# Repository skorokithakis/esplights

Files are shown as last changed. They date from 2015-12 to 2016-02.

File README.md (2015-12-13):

# ESPlights

This is a home automation controller and sensor that I wrote for my house.

It's mostly ad-hoc, but hopefully you'll find something here that will help you.

## Components

To make everything work, you need:

* A NodeMCU (that's what I used) or another compatible ESP8266 thing. An Arduino
  would probably also work.
* An infrared LED.
* A 433 MHz RF transmitter.
* An alarm (I used one of those magnetic window alarm thingies).
* An analog light sensor.
* A DHT11 temperature/humidity sensor.
* A pyroelectric IR motion sensor.

There are multiple components to this project, which will be explained below.

### A wifi-enabled MQTT client

I use the ESP8266 to connect to the home wifi network and from that to my MQTT
server, which allows all the below functionality to work. All the sensors and
transmitters report to and receive commands from MQTT topics.

### An RF transmitter

I bought some [RF-controlled
sockets](http://www.alibaba.com/product-detail/remote-control-socket-wireless-socket-rf_60038866245/showimage.html)
and decided to automate some lights in my house, so
I [reverse-engineered](http://www.stavros.io/posts/how-remote-control-rf-devices-raspberry-pi/)
the protocol and wrote some code to [control the lights
remotely](http://www.stavros.io/posts/control-rf-devices-with-arduino/). This is
why you need the RF transmitter. If you don't have those sockets, you can just
ignore that part of the code.

### A motion sensor

The motion sensor is used for the lights above, it turns them off if there's no
motion in X minutes and turns them back on if motion is detected.

### Light, temperature and humidity sensors

The light sensor is used for the lights too. If there's no light and there has
been motion lately, the lamp turns on, and it turns off if there's a lot of
light detected suddenly (it means that I turned some other light on).

The temperature and humidity sensors are just for fun.

### An alarm

The alarm is triggered if I have indicated that I'm not at home and motion is
detected. I also get a message on my phone, but all this is done with an
external script that is not included here.

### A universal IR remote control

Since I had this, I figured I'd write some code to control my TV and AC unit.
There's a helper script, `misc/esplights.py` that will:

* Transform timings, options, parameters, etc passed on the command line into a
  suitable format for the ESPlights controller to read.
* Enable and disable automation (whether lights are turned on or off
  automatically). This only lasts for a few hours before it times out.
* Activate and deactivate the alarm.
* Help you analyze timings. Pass it a CSV from a Saleae Logic export and it will
  print timings compatible with itself (for analyzing IR and RF signals).

The remote control protocol allows you to send any RF or IR signal (the pin is
selectable), and optionally add a carrier wave. The `duty_high` and `duty_low`
parameters define the duty cycle (in μs), and a low duty cycle of 0 means no
carrier (the timings will sent on a fully-high) signal. This allows you to
modulate everything from RF to AC to TV (all of which use different or no
carriers) through one protocol.

### A sensor aggregator

ESPlights will send its sensor readings to an MQTT topic once a second. I just
plot them somewhere so I know what's going on, but you can do whatever. I also
have an XMPP bot that I can talk to and get a reading of the sensors if I'm on
my mobile. Go nuts.

## Cetera

That's about it for this repo. It also supports OTA updates, which are very
useful if you don't want to be connecting the sensor to your computer to update
it. Just set the key in the definitions at the top of the source file and you're
good to flash using espota.

If you have any feedback or whatever, open an issue or (even better) issue a
pull request. I can't guarantee that I'll merge it, and I'm a bit of a dick, so
bear with me.

There's also a Fritzing file of roughly how the connections go, but it's not
complete because my components had the wrong pinouts and I couldn't find some of
the components I'm actually using. Feel free to update it and issue a PR.

Here's what it looks like:

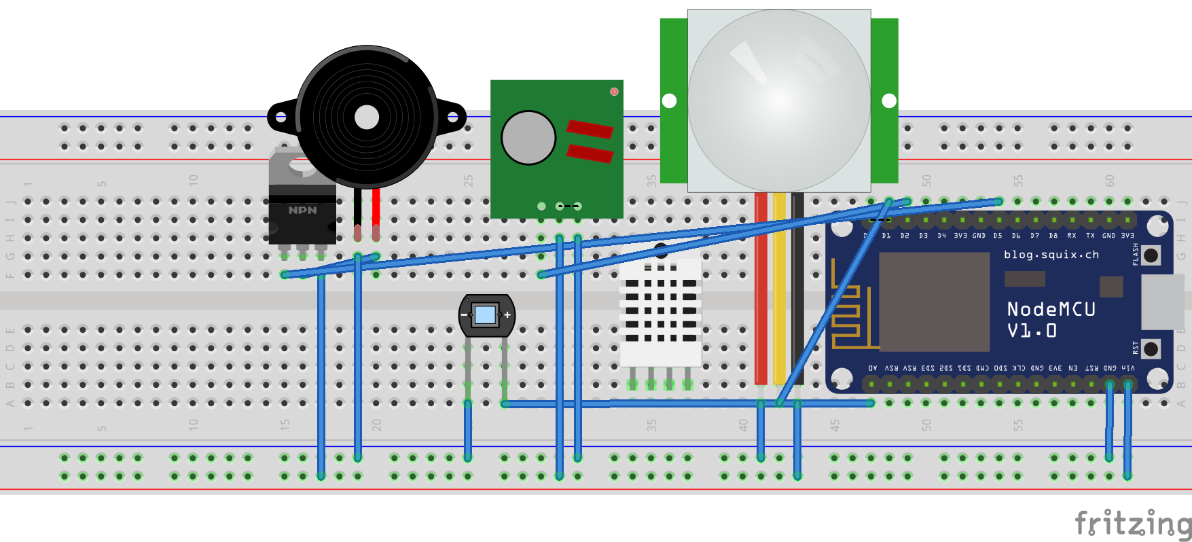
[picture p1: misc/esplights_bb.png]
The breadboard


## License

This repository is released under the GPL v3.

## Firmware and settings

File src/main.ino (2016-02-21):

#include "PubSubClient.h"
#include <EEPROM.h>
#include <ESP8266WiFi.h>
#include <ESP8266mDNS.h>
#include <WiFiUdp.h>
#include <ArduinoOTA.h>
#include <DHT.h>
#include "transmit.h"

#ifndef WIFI_SSID
#define WIFI_SSID "your ssid"
#endif

#ifndef WIFI_PASS
#define WIFI_PASS "your wifi password"
#endif

#ifndef OTA_PASS
#define OTA_PASS "an ota pass"
#endif

#define MQTT_ENABLED 1

#ifndef MQTT_SERVER
#define MQTT_SERVER "test.mosquitto.org"
#endif

#define MQTT_PORT 1883

#ifndef NTP_SERVER
#define NTP_SERVER "pool.ntp.org"
#endif

#define ACTIVE_MOTION_THRESHOLD 10 * 60
#define LIGHT_ON_THRESHOLD 90
#define LIGHT_OFF_THRESHOLD 200

#define MOTION_PIN D7
#define TEMPERATURE_PIN D6
#define LED_PIN D4
#define LED2_PIN D0
#define RF_PIN D1
#define ALARM_PIN D5
#define LIGHT_PIN A0

#define UPDATE_INTERVAL_MS 200
#define PUBLISH_STATE_MS 1000
#define MAX_MESSAGE_LENGTH 600
#define DELAY_MULTIPLIER 100
#define UNAUTO_DELAY 13 * 60 * 60L

#define CONFIG_VERSION "cf1"

WiFiClient wclient;
char COMMAND_CHANNEL[] = "esplights_command";
char STATE_CHANNEL[] = "esplights_state";
char LOG_CHANNEL[] = "esplights_log";
String NAME = "esplights1";

enum {OTA, CONNECTING_WIFI, CONNECTING_MQTT, CONNECTED} state = CONNECTING_WIFI;

#if MQTT_ENABLED == 1
PubSubClient client(wclient);
#endif

struct Sensors {
    unsigned long motion = 0;
    unsigned long motionTime = 0;
    unsigned int motionCounter = 0;
    unsigned int humidity = 0;
    unsigned int temperature = 0;
    unsigned int lightLevel = 0;
} sensors;

struct Persistent {
    char version[4] = CONFIG_VERSION;
    unsigned long autoDisableTime = 0;
    char automation = 1;
} persistent;

struct Misc {
    unsigned int lastUpdate = 0;
    unsigned int lastShow = 0;
    unsigned int alarm = 0;
    unsigned long bootTime = 0;
    char lampState = 0;
} misc;

unsigned char messageOn[] = {2, 113, 2, 113, 5, 32, 2, 113, 5, 12, 2, 113, 5, 12, 2, 113, 5, 32, 2, 113, 5, 12, 2, 134, 5, 12, 2, 113, 5, 12, 2, 134, 4, 247, 2, 155, 4, 247, 2, 134, 4, 247, 2, 134, 5, 12, 2, 134, 4, 247, 2, 155, 4, 226, 5, 12, 2, 92, 2, 155, 4, 205, 5, 12, 2, 92, 2, 155, 4, 247, 2, 134, 4, 247, 2, 134, 4, 247, 2, 155, 4, 226};
unsigned char messageOff[] = {2, 113, 2, 113, 5, 32, 2, 113, 5, 12, 2, 113, 5, 32, 2, 92, 5, 32, 2, 134, 5, 12, 2, 113, 5, 12, 2, 113, 5, 12, 2, 134, 4, 247, 2, 155, 4, 247, 2, 134, 5, 12, 2, 134, 4, 247, 2, 134, 4, 247, 2, 155, 4, 247, 5, 53, 2, 71, 2, 155, 4, 247, 2, 134, 4, 247, 2, 155, 4, 226, 2, 155, 4, 205, 2, 175, 4, 163, 5, 53, 2, 50};


// Publish a message to MQTT if connected.
void mqttPublish(String topic, String payload) {
#if MQTT_ENABLED == 1
    if (!client.connected()) {
        return;
    }
    client.publish(topic.c_str(), payload.c_str());
#endif
}


// Receive a message from MQTT and act on it.
#if MQTT_ENABLED == 1
void mqttCallback(char* chTopic, byte* chPayload, unsigned int length) {
    chPayload[length] = '\0';
    String payload = String((char*)chPayload);

    if (payload == "auto on") {
        enableAuto(1);
    } else if (payload == "auto off") {
        enableAuto(0);
    } else if (payload == "alarm on") {
        misc.alarm = 1;
        digitalWrite(ALARM_PIN, HIGH);
    } else if (payload == "alarm off") {
        misc.alarm = 0;
        digitalWrite(ALARM_PIN, LOW);
    } else if (payload[0] == 1) {
        cmdSend(chPayload[3], &chPayload[6], chPayload[4], chPayload[5] * DELAY_MULTIPLIER, chPayload[1] - 1,  chPayload[2] - 1);
    }
}
#endif


// Send a command, printing some debug information.
void cmdSend(char pin, unsigned char message[], unsigned char repeat, unsigned int intraDelay, unsigned char dcHigh, unsigned char dcLow) {
    unsigned int out = 0;
    unsigned int i;

    digitalWrite(LED2_PIN, LOW);

    Serial.print("Sending on pin ");
    Serial.print(pin, DEC);
    Serial.print(", repeating ");
    Serial.print(repeat, DEC);
    Serial.print(" times, for ");
    Serial.print(intraDelay);
    Serial.print(" with a high duty cycle of ");
    Serial.print(dcHigh, DEC);
    Serial.print(" and a low duty cycle of ");
    Serial.print(dcLow, DEC);
    Serial.println(".");

    // Print the received timings to the console.
    for (i = 0; i < MAX_MESSAGE_LENGTH; i = i + 2) {
        if (message[i] == 0 || message[i+1] == 0) {
            break;
        }
        out = (message[i] << 8) + message[i+1];
        Serial.print(out, DEC);
        Serial.print(" ");
    }
    Serial.println("");
    yield();

    transmit(pin, message, repeat, intraDelay, dcHigh, dcLow);

    Serial.println("Command sent.");
    digitalWrite(LED2_PIN, HIGH);
}


unsigned long getNTPTime() {
    IPAddress address;
    WiFiUDP udp;
    const int NTP_PACKET_SIZE = 48;
    byte packetBuffer[NTP_PACKET_SIZE];

    udp.begin(2390);
    // set all bytes in the buffer to 0
    memset(packetBuffer, 0, NTP_PACKET_SIZE);
    // Initialize values needed to form NTP request
    // (see URL above for details on the packets)
    packetBuffer[0] = 0b11100011;   // LI, Version, Mode
    packetBuffer[1] = 0;     // Stratum, or type of clock
    packetBuffer[2] = 6;     // Polling Interval
    packetBuffer[3] = 0xEC;  // Peer Clock Precision
    // 8 bytes of zero for Root Delay & Root Dispersion
    packetBuffer[12]  = 49;
    packetBuffer[13]  = 0x4E;
    packetBuffer[14]  = 49;
    packetBuffer[15]  = 52;

    // all NTP fields have been given values, now
    // you can send a packet requesting a timestamp:
    WiFi.hostByName(NTP_SERVER, address);
    udp.beginPacket(address, 123); //NTP requests are to port 123
    udp.write(packetBuffer, NTP_PACKET_SIZE);
    udp.endPacket();

    delay(1000);

    int cb = udp.parsePacket();
    if (!cb) {
        return 0;
    } else {
        udp.read(packetBuffer, NTP_PACKET_SIZE);
        unsigned long highWord = word(packetBuffer[40], packetBuffer[41]);
        unsigned long lowWord = word(packetBuffer[42], packetBuffer[43]);
        unsigned long secsSince1900 = highWord << 16 | lowWord;
        const unsigned long seventyYears = 2208988800UL;
        unsigned long epoch = secsSince1900 - seventyYears;
        return epoch;
    }
}


void resetPins() {
    pinMode(1, OUTPUT);
    digitalWrite(1, LOW);
    pinMode(2, OUTPUT);
    digitalWrite(2, LOW);
    pinMode(3, OUTPUT);
    digitalWrite(3, LOW);
    pinMode(4, OUTPUT);
    digitalWrite(4, LOW);
    pinMode(5, OUTPUT);
    digitalWrite(5, LOW);
    pinMode(12, OUTPUT);
    digitalWrite(12, LOW);
    pinMode(13, OUTPUT);
    digitalWrite(13, LOW);
    pinMode(14, OUTPUT);
    digitalWrite(14, LOW);
    pinMode(15, OUTPUT);
    digitalWrite(15, LOW);
}

void loadState() {
    if (EEPROM.read(0) == CONFIG_VERSION[0] &&
        EEPROM.read(1) == CONFIG_VERSION[1] &&
        EEPROM.read(2) == CONFIG_VERSION[2]) {
        for (unsigned int t=0; t<sizeof(persistent); t++)
            *((char*)&persistent + t) = EEPROM.read(t);
    }
}


void saveState() {
    for (unsigned int t=0; t<sizeof(persistent); t++)
        EEPROM.write(t, *((char*)&persistent + t));
    EEPROM.commit();
}


unsigned long currentTime() {
    return misc.bootTime + (millis() / 1000);
}


// Enable or disable automation.
void enableAuto(char enable) {
    if (enable == 0) {
        persistent.autoDisableTime = currentTime() + UNAUTO_DELAY;
    } else {
        persistent.autoDisableTime = 0;
    }
    persistent.automation = enable;
    saveState();
}


void checkTimers() {
    if ((persistent.automation == 0) && ((currentTime() > persistent.autoDisableTime))) {
        enableAuto(1);
    }
}


// Return a JSON string of the entire state of the inputs.
String sensorState() {
    return String(String("{\n") +
                  "\"LAST_MOTION_SEC\": " + String((unsigned long)((millis() / 1000) - sensors.motionTime), DEC) + ",\n" +
                  "\"MOTION_COUNTER\": " + String(sensors.motionCounter, DEC) + ",\n" +
                  "\"ALARM\": " + String(misc.alarm, DEC) + ",\n" +
                  "\"HUMIDITY\": " + String(sensors.humidity, DEC) + ",\n" +
                  "\"TEMPERATURE\": " + String(sensors.temperature, DEC) + ",\n" +
                  "\"LIGHT_LEVEL\": " + String(sensors.lightLevel, DEC) + ",\n" +
                  "\"LAMP_STATE\": " + String(misc.lampState, DEC) + ",\n" +
                  "\"AUTOMATION\": " + String(persistent.automation, DEC) + ",\n" +
                  "\"AUTO_DISABLE_TIME\": " + String(persistent.autoDisableTime, DEC) + ",\n" +
                  "\"CURRENT_TIME\": " + String(currentTime(), DEC) + ",\n" +
                  "}\n");
}


// Decide whether to control the light.
void decide() {
    unsigned long lastMotionSec = (millis() / 1000) - sensors.motionTime;
    unsigned int lightLevel = analogRead(LIGHT_PIN);

    if (persistent.automation == 0) {
        // Do nothing if we aren't managing the thing.
        return;
    }

    if ((lastMotionSec < ACTIVE_MOTION_THRESHOLD) &&
            (sensors.lightLevel < LIGHT_ON_THRESHOLD) &&
            (misc.lampState == 0)) {
        // Turn on if motion is detected and there is no light.
        cmdSend(RF_PIN, messageOn, 3, 10000, 0, 0);
        misc.lampState = 1;
        mqttPublish(LOG_CHANNEL, "Turning on...");
    } else if ((lastMotionSec >= ACTIVE_MOTION_THRESHOLD) &&
               (misc.lampState == 1)) {
        // Turn off if motion is not detected for some time.
        cmdSend(RF_PIN, messageOff, 3, 10000, 0, 0);
        misc.lampState = 0;
        mqttPublish(LOG_CHANNEL, "Turning off because of motion...");
    } else if ((sensors.lightLevel > LIGHT_OFF_THRESHOLD) && (misc.lampState == 1)) {
        // Turn off if other lights are turned on.
        cmdSend(RF_PIN, messageOff, 3, 10000, 0, 0);
        misc.lampState = 0;
        mqttPublish(LOG_CHANNEL, "Turning off because of lights...");
    }
}


// Update the sensors to their latest values.
void updateSensors() {
    char motionInput = 0;

    motionInput = digitalRead(MOTION_PIN);
    digitalWrite(LED_PIN, !motionInput);

    // Check last update.
    if (millis() > misc.lastUpdate + UPDATE_INTERVAL_MS) {
        misc.lastUpdate = millis();
    } else {
        return;
    }

    // Check motion.
    Serial.println(motionInput, DEC);

    if (motionInput) {
        sensors.motionTime = millis() / 1000;
    }

    if ((motionInput == 1) && (sensors.motion == 0)) {
        sensors.motionCounter++;
    }
    sensors.motion = motionInput;
    sensors.lightLevel = analogRead(LIGHT_PIN);

    // We don't need to read this every second.
    if (millis() % 10 == 0) {
        DHT sensor(TEMPERATURE_PIN, DHT11);

        sensors.humidity = sensor.readHumidity();
        sensors.temperature = sensor.readTemperature();
    }
    decide();
}


// Publish our current sensor readings to MQTT.
void publishState() {
    // Check last update.
    if (millis() > misc.lastShow + PUBLISH_STATE_MS) {
        misc.lastShow = millis();
    } else {
        return;
    }

    mqttPublish(STATE_CHANNEL, sensorState());
}


// Check the MQTT connection and reboot if we can't connect.
void connectMQTT() {
#if MQTT_ENABLED == 1
    if (state == OTA) return;

    if (client.connected()) {
        client.loop();
        state = CONNECTED;
    } else {
        state = CONNECTING_MQTT;

        int retries = 4;
        Serial.println("\nConnecting to MQTT...");
        while (!client.connect(NAME.c_str()) && retries--) {
            delay(500);
            Serial.println("Retry...");
        }

        if (!client.connected()) {
            Serial.println("\nfatal: MQTT server connection failed. Rebooting.");
            delay(200);
            ESP.restart();
        }

        Serial.println("Connected.");
        client.subscribe(COMMAND_CHANNEL);
    }
#endif
}


// Check the WiFi connection and connect if it's down.
void connectWifi() {
    if (WiFi.waitForConnectResult() != WL_CONNECTED) {
        state = CONNECTING_WIFI;

        WiFi.mode(WIFI_STA);
        while (WiFi.waitForConnectResult() != WL_CONNECTED) {
            WiFi.begin(WIFI_SSID, WIFI_PASS);
            Serial.println("Connecting to wifi...");
        }

        Serial.print("Wifi connected, IP address: ");
        Serial.println(WiFi.localIP());
    }

    state = CONNECTING_MQTT;
}


void setup() {
    resetPins();
    Serial.begin(115200);
    EEPROM.begin(32);
    loadState();

    pinMode(MOTION_PIN, INPUT);
    pinMode(LIGHT_PIN, INPUT);
    pinMode(LED_PIN, OUTPUT);
    pinMode(LED2_PIN, OUTPUT);
    pinMode(RF_PIN, OUTPUT);
    pinMode(ALARM_PIN, OUTPUT);
    digitalWrite(LED2_PIN, HIGH);
    digitalWrite(ALARM_PIN, LOW);

#if MQTT_ENABLED == 1
    client.setServer(MQTT_SERVER, MQTT_PORT);
    client.setCallback(mqttCallback);
#endif

    connectWifi();
    connectMQTT();
    state = CONNECTED;

    misc.bootTime = getNTPTime() - (millis() / 1000);

    // Enable OTA updates.
    ArduinoOTA.setPassword((const char *) OTA_PASS);
    ArduinoOTA.setHostname("ESPlights");

    ArduinoOTA.onStart([]() {
            Serial.println("Start");
            state = OTA;
            });
    ArduinoOTA.onEnd([]() {
            Serial.println("\nEnd");
            });
    ArduinoOTA.onProgress([](unsigned int progress, unsigned int total) {
            Serial.printf("Progress: %u%%\r", (progress / (total / 100)));
            });
    ArduinoOTA.onError([](ota_error_t error) {
            Serial.printf("Error[%u]: ", error);
            if (error == OTA_AUTH_ERROR) Serial.println("Auth Failed");
            else if (error == OTA_BEGIN_ERROR) Serial.println("Begin Failed");
            else if (error == OTA_CONNECT_ERROR) Serial.println("Connect Failed");
            else if (error == OTA_RECEIVE_ERROR) Serial.println("Receive Failed");
            else if (error == OTA_END_ERROR) Serial.println("End Failed");
            });
    ArduinoOTA.begin();
}


void loop() {
    connectWifi();
    connectMQTT();

    state = CONNECTED;

    checkTimers();
    updateSensors();
    publishState();

    ArduinoOTA.handle();
}

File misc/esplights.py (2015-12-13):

#!/usr/bin/env python
"""Usage:
  arduirc.py [options] send ( <section> <command> | <timings> )
  arduirc.py analyze <timings_csv>
  arduirc.py automation ( enable | disable )
  arduirc.py alarm ( enable | disable )

Options:
  -h --help               show this help and exit
  -s --server=HOSTNAME    the MQTT server to connect to [default: localhost].
  -u --duty-high=USEC     the high part of the duty cycle in usec (0-255) [default: 26]
  -l --duty-low=USEC      the low part of the duty cycle in usec (0-255) [default: 0]
  -v --version            show version and exit
  -t --timings-file=FILE  specify the timings file to use [default: timings.yml]
  -w --wait               wait two seconds for the Arduino to reset.
  -r --repeat=REPEAT      repeat the command REPEAT times [default: 3]
  -d --delay=DELAY        delay between repeats (in usec) [default: 10000]
  -p --pin=PIN            which GPIO pin to write to [default: 4]
"""

import csv
import sys
import yaml
import struct

from docopt import docopt
import paho.mqtt.client as mqtt


def mqtt_send(server, payload):
    # chr(1) is the command (command 1, send timings).
    client = mqtt.Client()
    client.connect(server)
    client.publish("esplights_command", bytearray(payload))


def send(arguments):
    # Get the timings.
    pin = int(arguments["--pin"])
    repeat = int(arguments["--repeat"])
    delay = int(round(int(arguments["--delay"]) / 100.0))
    duty_high = max(1, int(arguments["--duty-high"]) + 1)
    duty_low = max(1, int(arguments["--duty-low"]) + 1)

    if arguments.get("<section>") and arguments.get("<command>"):
        section = arguments["<section>"]
        command = arguments["<command>"]

        try:
            timing_dict = yaml.load(open(arguments["--timings-file"]))
        except IOError:
            sys.exit("Error opening timings file.")

        if section not in timing_dict:
            sys.exit("Unknown section.")

        if command not in timing_dict[section]["timings"]:
            sys.exit("Unknown command.")

        raw_timings = timing_dict[section]["timings"][command]

        # Override the command line with the parameters in the file.
        params = timing_dict[section].get("parameters", {})
        pin = params.get("pin", pin)
        duty_high = params.get("duty_high", duty_high)
        duty_low = params.get("duty_low", duty_low)
        repeat = params.get("repeat", repeat)
        delay = params.get("delay", delay)

    elif arguments.get("<timings>"):
        raw_timings = arguments["<timings>"]

    timings = [int(timing) for timing in raw_timings.split()]

    output = struct.pack("!" + ("h" * len(timings)), *timings)
    output = output.replace(chr(0), chr(1))  # Can't have null bytes.

    if delay > 255 or delay < 1:
        sys.exit("Delay must be between 100 and 25500.")

    if pin > 13 or pin < 0:
        sys.exit("Pin must be between 0 and 13.")

    if repeat > 255 or repeat < 1:
        sys.exit("Repeat must be between 1 and 255.")

    output = chr(1) + chr(duty_high) + chr(duty_low) + chr(pin) + chr(repeat) + chr(delay) + output + chr(0)
    mqtt_send(arguments["--server"], output)

    print("Command sent.")


def automation(enable):
    if arguments["enable"]:
        mqtt_send(arguments["--server"], "auto on")
    else:
        mqtt_send(arguments["--server"], "auto off")
    print("Command sent.")


def alarm(enable):
    if arguments["enable"]:
        mqtt_send(arguments["--server"], "alarm on")
    else:
        mqtt_send(arguments["--server"], "alarm off")
    print("Command sent.")


def analyze(arguments):
    """
    Read a CSV file from a logic analyzer and print out a send-compatible
    timings list.
    """
    reader = csv.reader(open(arguments["<timings_csv>"]))

    # Read and convert seconds to microseconds.
    timings = [int(1000000 * float(x[0])) for x in reader]

    # Normalize to 0 as the first value.
    timings = [x - timings[0] for x in timings]

    # Calculate the differences.
    diffs = [x[0] - x[1] for x in zip(timings[1:], timings)]
    print "Timings: %s" % " ".join([str(x) for x in diffs])


def main(arguments):
    if arguments["send"]:
        send(arguments)
    elif arguments["automation"]:
        automation(arguments)
    elif arguments["alarm"]:
        alarm(arguments)
    elif arguments["analyze"]:
        analyze(arguments)


if __name__ == "__main__":
    arguments = docopt(__doc__, version="0.1.0")
    main(arguments)
